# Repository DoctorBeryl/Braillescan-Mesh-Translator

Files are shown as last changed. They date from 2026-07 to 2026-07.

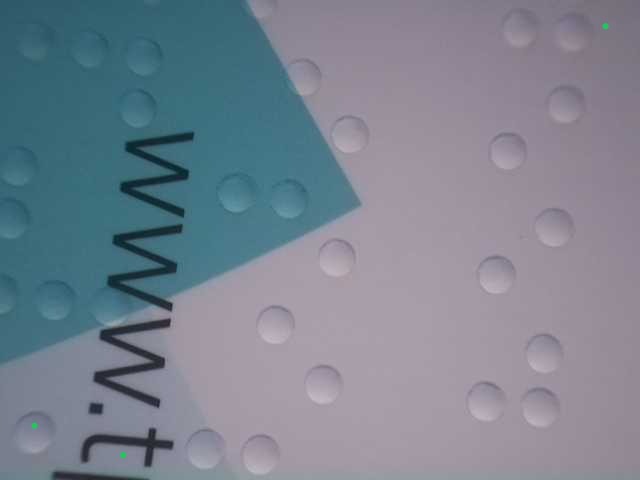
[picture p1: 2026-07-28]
test_images/input/img-1785229373890.jpg

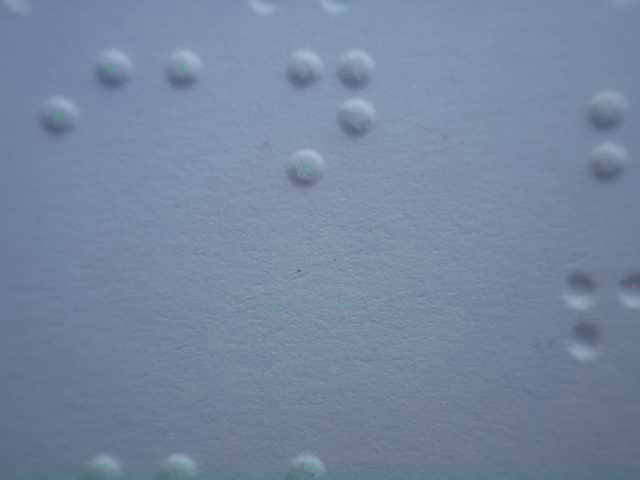
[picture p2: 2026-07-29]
test_images/input/clean2.jpg

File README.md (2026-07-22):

# BrailleScan Mesh Translator

**Dispozitiv bazat pe Raspberry Pi care recunoaște și traduce text Braille și text tipărit, utilizând o cameră cu lentilă macro, senzori, o interfață web și un afișaj LCD.**

---

### Documentele esențiale:

| Document | Link |
|---|---|
| **DOCUMENTATIE** | [Documentatie](#descrierea-problemei-pe-care-o-rezolvăm) |
| **COMENZI SETUP** | [SETUP_COMMANDS.txt](./SETUP_COMMANDS.txt) |
| **Hardware Necesar** | [Hardware](#cerințe-hardware) |
| **Modele 3D** | [3dmodels/](./3dmodels/) |

---

## Comenzi Rapide - Setup Website

```bash
git clone https://github.com/DoctorBeryl/Braillescan-Mesh-Translator.git
cd Braillescan-Mesh-Translator
npm install
npm install concurrent --save-dev
npm run dev
```

Accesare: http://192.168.100.184:3000

**Instalare completă:** [SETUP_COMMANDS.txt](./SETUP_COMMANDS.txt)

---

## Stack Tehnologic

- **Frontend:** React 19, Vite 8, Tailwind CSS 4
- **Backend:** Node.js, Express 5
- **Hardware:** libcamera/rpicam, nmcli, I2C/SPI
- **Tools:** Oxlint, Concurrently

---

## Dependințe

### Runtime
| Pachet | Versiune | Scop |
|---|---|---|
| react | ^19.2.7 | Framework UI |
| express | ^5.1.0 | Server HTTP |
| @google/model-viewer | ^4.3.1 | Vizualizare 3D |
| @vitalets/google-translate-api | ^9.2.1 | Traducere |
| lucide-react | ^1.24.0 | Pictograme |

### Sistem
- Raspberry Pi 3 A+ (sau mai nou)
- Raspberry Pi OS Bookworm
- Node.js 18+
- libcamera/rpicam
- i2c-tools

---

## Cerințe Hardware

- Raspberry Pi 3 A+ (Pi 4/5 recomandat)
- Card microSD 32GB+
- Sursă 5V/2A
- Camera Raspberry Pi Module 3 cu lentilă macro
- Display LCD I2C/SPI (16x2 sau 20x4)
- Senzori distanță (VL53L0X)
- Wi-Fi încorporat

**Modele 3D:** Disponibile în directorul `3dmodels/` pentru tipărire

---

## Cuprins

- [Descrierea Problemei](#descrierea-problemei-pe-care-o-rezolvăm)
- [Soluția Propusă](#descrierea-soluției-propuse)
- [Publicul Țintă](#definirea-publicului-țintă)
- [Funcționalități](#prezentarea-funcționalităților-aplicației)
- [Arhitectura](#arhitectura-aplicației)
- [Puncte Forte](#elemente-distinctive-ale-aplicației--puncte-forte)
- [Justificare Tehnologii](#justificarea-folosirii-tehnologiilor-alese)
- [Opinia Autorilor](#opinia-autorilor-despre-proiect)
- [Roadmap](#roadmap)

---

# BrailleScan Mesh Translator — Documentație proiect

## Descrierea problemei pe care o rezolvăm

Accesul persoanelor cu deficiențe de vedere la informațiile scrise
reprezintă încă o provocare majoră. Deși sistemul Braille este
standardul internațional pentru citirea tactilă, un număr redus de
persoane din populația generală cunosc acest sistem de scriere. În
consecință, membrii familiei, profesorii, voluntarii sau alte persoane
care interacționează cu utilizatorii nevăzători întâmpină dificultăți în
interpretarea documentelor redactate în Braille.

Pe de altă parte, dispozitivele realizate în cadrul unor programe
universitare sau a unor producători comerciali, dedicate traducerii
Braille în text obișnuit, nu sunt accesibile publicului, iar costurile
acestora se ridică la sute sau chiar mii de dolari. Acestea utilizează
componente specializate și oferă o flexibilitate redusă în ceea privește
costurile. De asemenea, majoritatea soluțiilor existente sunt orientate
exclusiv către conversia textului tipărit în Braille sau necesită
echipamente profesionale pentru scanare.

BrailleScan Mesh Translator își propune să elimine aceste limitări prin
dezvoltarea unui dispozitiv accesibil, portabil și ușor de utilizat,
capabil să traducă atât textul Braille embosat, cât și textul tipărit
obișnuit, utilizând tehnologii moderne de procesare a imaginilor și
senzori dedicați.

## Descrierea soluției propuse

BrailleScan Mesh Translator este un aparat electronic
construit în jurul unui microcalculator Raspberry Pi. Dispozitivul
utilizează o cameră echipată cu lentilă macro pentru captarea în detaliu
a suprafeței hârtiei embosate și senzori care permit analizarea
reliefului caracterelor Braille.

Imaginea captată este procesată, fiind identificată poziția punctelor
Braille și reconstruit caracterul corespunzător. Rezultatul este apoi
tradus automat în alfabetul latin și afișat pe interfața web.
Totodată, aparatul oferă indicații în timp real despre poziția optimă a
camerei pe un ecran LCD integrat.

În plus, dispozitivul poate funcționa și ca un scanner OCR pentru text
obișnuit, utilizând aceeași cameră și algoritmi de recunoaștere optică a
caracterelor.

Întregul sistem este accesibil prin intermediul unei aplicații web
găzduite chiar pe Raspberry Pi, fără a necesita instalarea unui software
suplimentar pe calculatorul utilizatorului. De asemenea, aparatul este
portabil, fiind încadrat într-un cadru printat 3D, ceea ce îi permite
utilizarea în contexte diverse. Acesta nu depinde permanent de o sursă
fixă de curent.

## Definirea publicului țintă

Proiectul este destinat în principal:

- Persoanelor cu deficiențe de vedere
- Profesorilor care predau alfabetul Braille
- Instituțiilor de învățământ special
- Bibliotecilor pentru nevăzători
- Membrilor familiei persoanelor nevăzătoare
- Voluntarilor și organizațiilor care lucrează în domeniul incluziunii sociale

De asemenea, dispozitivul poate fi utilizat în scop educațional pentru
familiarizarea persoanelor fără deficiențe de vedere cu sistemul Braille.

## Prezentarea funcționalităților aplicației

Principalele funcționalități ale sistemului sunt:

- Recunoașterea caracterelor Braille utilizând camera macro și senzorii dedicați
- Traducerea automată a textului Braille în alfabetul latin
- Recunoașterea textului tipărit prin tehnologia OCR
- Afișarea indicațiilor în timp real pe display-ul LCD
- Reconstruirea unei reprezentări 3D a textului Braille
- Accesarea unei interfețe web moderne prin intermediul browserului
- Funcționarea independentă într-o rețea Wi-Fi creată de Raspberry Pi
- Posibilitatea conectării la Internet printr-o a doua interfață wireless
- Administrarea și configurarea dispozitivului din interfața web

## Arhitectura aplicației

Sistemul este alcătuit din două componente principale:

**Dispozitivul Raspberry Pi** - Nucleul aplicației:
- Rularea sistemului de operare Linux
- Controlul camerei și al senzorilor
- Capturarea și distribuirea imaginilor pentru procesare
- Găzduirea aplicației web
- Streamingul camerei live pe interfață
- Administrarea rețelei locale

Raspberry Pi creează o rețea Wi-Fi proprie (Access Point). Opțional, poate folosi o a doua interfață Wi-Fi pentru conectarea la Internet. Hardware-ul este montat într-un cadru printat 3D modular. Dispozitivul necesită 5V la 2A. Utilizarea unui acumulator portabil permite funcționarea mobilă.

**Dispozitivul Host** - Orice calculator, tabletă sau telefon mobil cu browser web modern care comunică prin HTTP cu dispozitivul.

## Elemente distinctive ale aplicației — puncte forte

- Captură de imagini în mod macro pentru analizarea reliefului Braille
- Combinarea informațiilor provenite din senzori și procesarea imaginilor
- Suport simultan pentru traducerea Braille și OCR
- Traducerea directă în sau din diferite limbi străine
- Funcționalitate offline
- Interfață web multiplatformă, fără aplicații dedicate
- Cost redus comparativ cu echipamentele comerciale
- Arhitectură modulară și extensibilă

## Justificarea folosirii tehnologiilor alese

Platforma Raspberry Pi 3 A+ oferă un raport excelent între performanță, consum energetic și cost. Dispune de suficientă putere de procesare pentru analizarea imaginilor în timp real și permite integrarea facilă cu camere și senzori. Linux oferă stabilitate și suport extins pentru biblioteci open-source.

Interfața web este independentă de sistemul de operare și poate fi accesată de pe orice dispozitiv cu browser. Camera cu lentilă macro permite captarea fidelă a reliefului Braille. Alegerea acestor tehnologii conduce la un sistem flexibil, ușor de întreținut și extensibil.

## Opinia autorilor despre proiect

Considerăm că beneficiile tehnologiei trebuie să fie disponibile unui
număr cât mai mare de persoane. Asistența persoanelor cu dizabilități
reprezintă un scop important al acestui proiect. Noi am realizat
o soluție bazată pe componente relativ accesibile.

Un profesor care primește o lucrare redactată în Braille poate utiliza
BrailleScan Mesh Translator pentru a obține rapid traducerea în alfabetul latin.
Membrii familiei pot înțelege mai ușor mesajele scrise în Braille,
facilitând comunicarea zilnică.

## Roadmap

Pentru etapele ulterioare ale dezvoltării propunem:

- Creșterea vitezei de recunoaștere
- Integrarea unui display Braille reîmprospătabil pentru conversia inversă
- Integrarea unui sintetizator vocal
- Dezvoltarea unei aplicații mobile dedicate
- Sincronizarea cu servicii cloud
- Îmbunătățirea autonomiei și optimizarea designului cadrului printat 3D
- Integrarea sistemelor de inteligență artificială pentru optimizarea recunoașterii
- Implementarea unui sistem autofocus pentru cameră

**Repository:** https://github.com/DoctorBeryl/Braillescan-Mesh-Translator
**Mentenanță:** [@DoctorBeryl](https://github.com/DoctorBeryl)

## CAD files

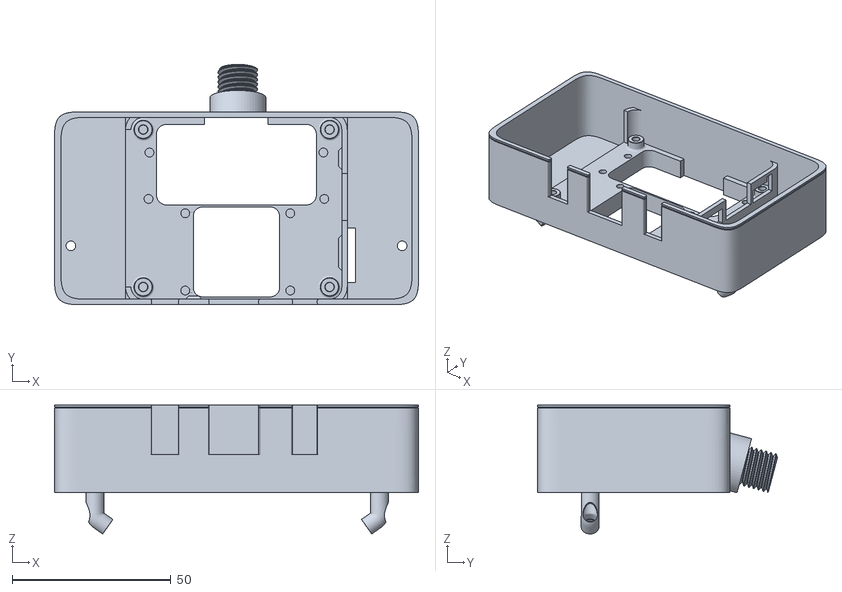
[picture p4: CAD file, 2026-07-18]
3dmodels/MainHolder.stl
114.7 x 75.7 x 40.6

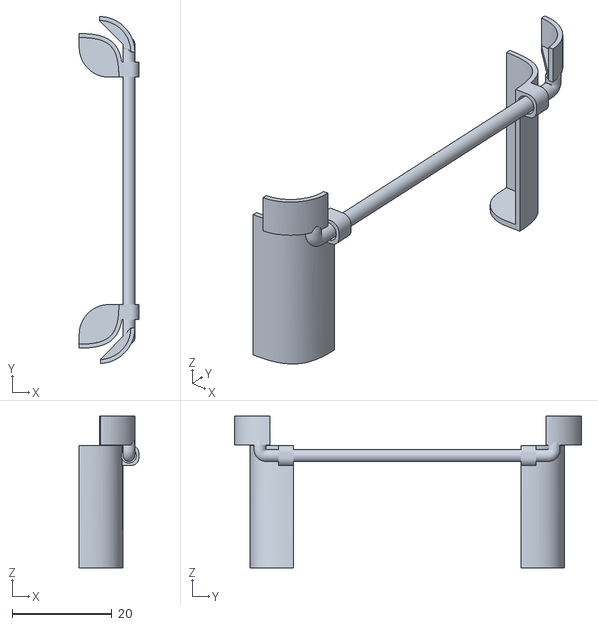
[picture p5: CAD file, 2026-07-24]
3dmodels/coverextras2.stl
12.0 x 69.5 x 30.4

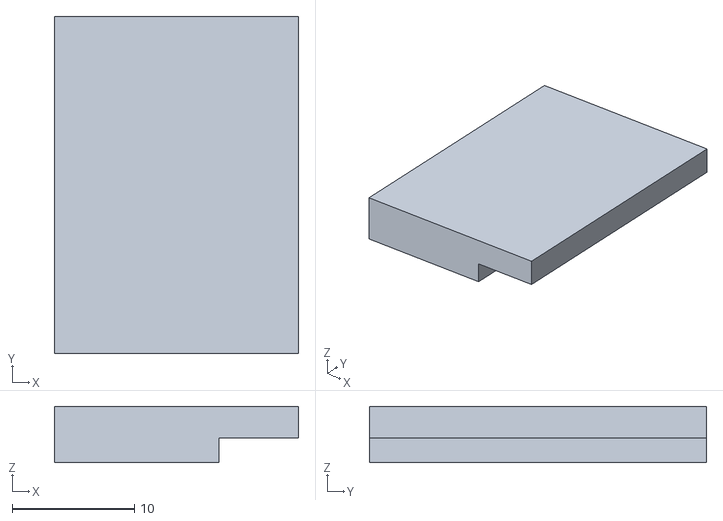
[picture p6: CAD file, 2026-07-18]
3dmodels/CameraExtras.stl
20.0 x 27.6 x 4.60

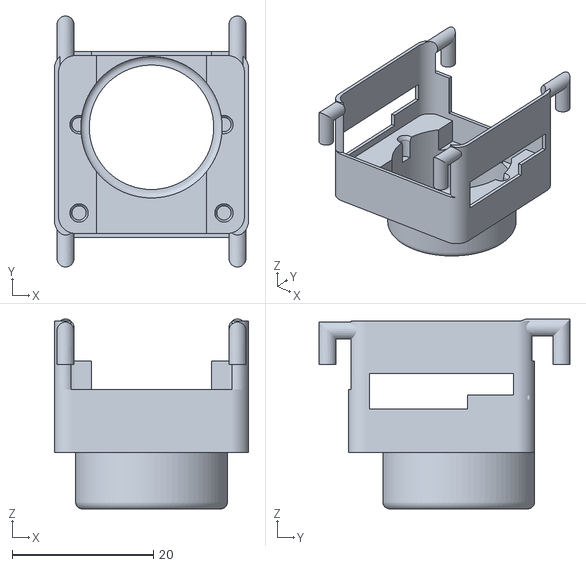
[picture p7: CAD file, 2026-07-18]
3dmodels/RaspberryPiCameraModule3Cover.stl
27.5 x 35.5 x 26.9

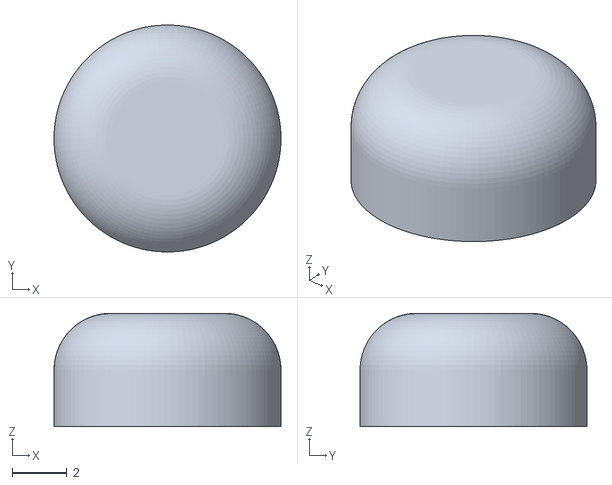
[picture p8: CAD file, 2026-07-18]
3dmodels/CoverExtras.stl
8.32 x 8.32 x 4.16

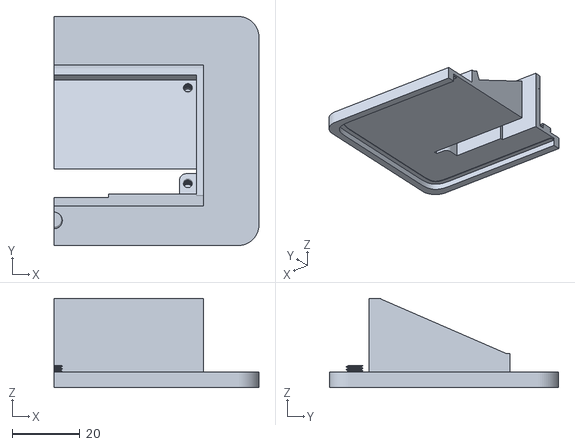
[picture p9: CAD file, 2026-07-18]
3dmodels/CoverRight.stl
60.4 x 67.5 x 26.3

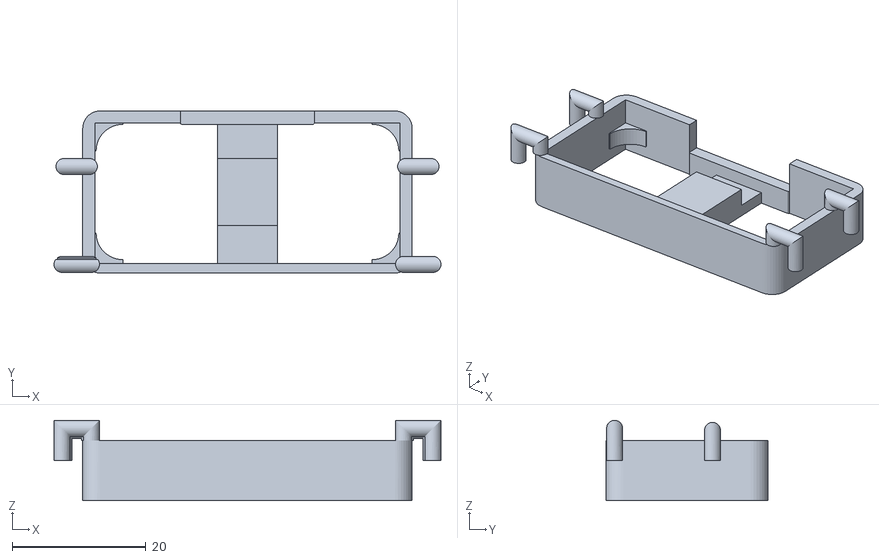
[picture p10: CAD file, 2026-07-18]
3dmodels/DistanceSensorCover.stl
57.8 x 24.2 x 12.0

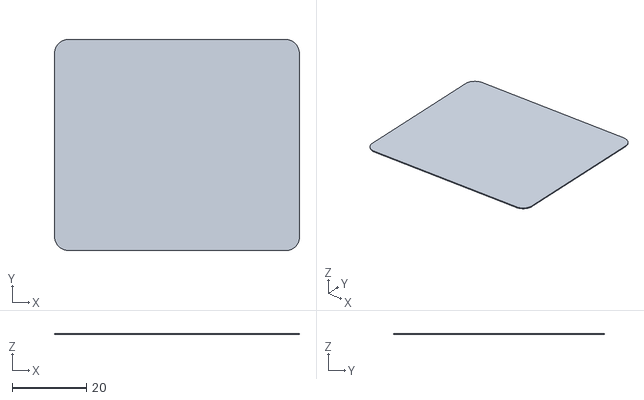
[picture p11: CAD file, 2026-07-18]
3dmodels/RaspberryPiFlooring.stl
66.0 x 56.9 x 0.3

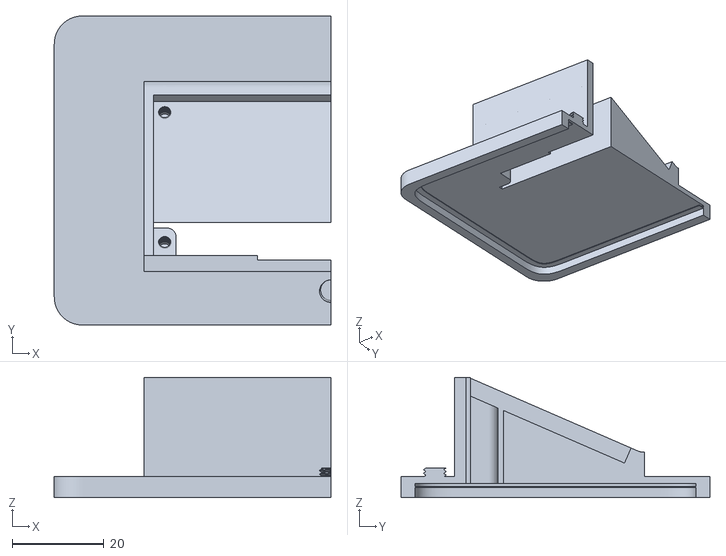
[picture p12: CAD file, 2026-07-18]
3dmodels/CoverLeft.stl
60.4 x 67.5 x 26.3

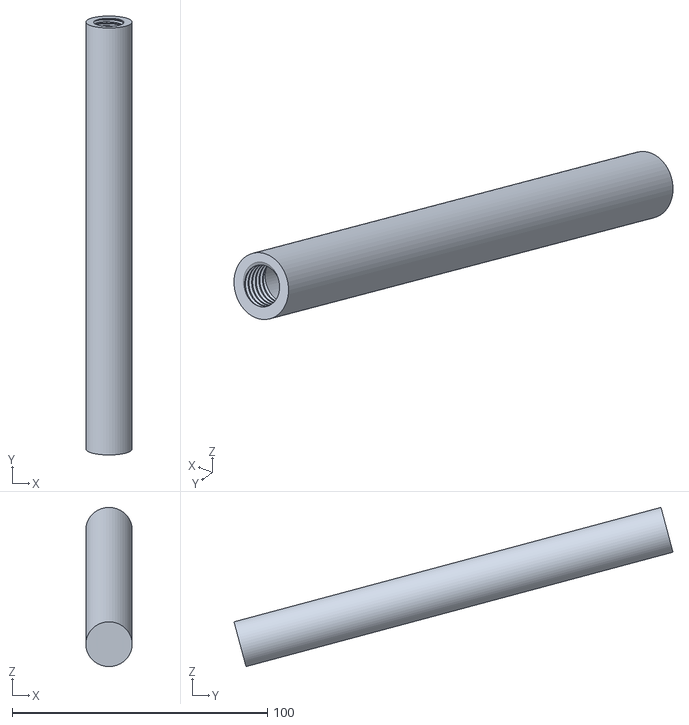
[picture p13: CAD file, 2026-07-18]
3dmodels/Handle.stl
18.1 x 172.1 x 62.4

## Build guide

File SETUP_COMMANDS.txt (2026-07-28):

================================================================================
    BRAILLESCAN MESH TRANSLATOR - COMENZI SETUP (MINIM)
================================================================================

CUPRINS:
  1. Setup Dezvoltare (Calculator Local)
  2. Instalare Raspberry Pi OS
  3. Setup Inițial Sistem
  4. Instalare Aplicație pe Raspberry Pi
  5. Pornire Aplicație
  6. Setup Serviciu Systemd (Auto-start)
  7. Ecran LCD 16x2 (Instrucțiuni la Boot)
  8. Permisiuni Admin (Reboot / Poweroff din interfața web)

================================================================================
1. SETUP DEZVOLTARE (Calculator Local)
================================================================================

Clonare și setup:
  git clone https://github.com/DoctorBeryl/Braillescan-Mesh-Translator.git
  cd Braillescan-Mesh-Translator
  npm install

Pornire:
  npm run dev

Build producție:
  npm run build
  npm run server

================================================================================
2. INSTALARE RASPBERRY PI OS
================================================================================

1. Descărcați Raspberry Pi Imager: https://www.raspberrypi.com/software/
2. Selectați: Raspberry Pi OS Lite 64-bit
3. Flash pe card microSD
4. Boot și conectare SSH: ssh pi@raspberrypi.local

================================================================================
3. SETUP INIȚIAL SISTEM
================================================================================

Update sistem:
  sudo apt update && sudo apt upgrade -y

Activare interfețe (raspi-config):
  sudo raspi-config
  # Interfacing Options → Camera, I2C, SPI, SSH → Enable
  # Reboot

Instalare dependințe:
  sudo apt install -y git curl build-essential libcamera-apps i2c-tools
  curl -fsSL https://deb.nodesource.com/setup_20.x | sudo -E bash -
  sudo apt install -y nodejs npm

================================================================================
4. INSTALARE APLICAȚIE PE RASPBERRY PI
================================================================================

Clonare și setup:
  cd ~
  git clone https://github.com/DoctorBeryl/Braillescan-Mesh-Translator.git
  cd Braillescan-Mesh-Translator
  npm install

================================================================================
5. PORNIRE APLICAȚIE
================================================================================

Pornire mod dezvoltare:
  cd ~/Braillescan-Mesh-Translator
  npm run dev

Accesare browser:
  http://192.168.100.184:3000
  
================================================================================
6. SETUP SERVICIU SYSTEMD (Auto-start la Boot)
================================================================================

Creare serviciu:
  sudo nano /etc/systemd/system/braillescan.service

Adăugați:
---
[Unit]
Description=BrailleScan Mesh Translator
After=network.target

[Service]
Type=simple
User=pi
WorkingDirectory=/home/pi/Braillescan-Mesh-Translator
ExecStart=/usr/bin/npm run dev
Restart=always

[Install]
WantedBy=multi-user.target
---

Salvare (Ctrl+X, Y, Enter)

Activare:
  sudo systemctl daemon-reload
  sudo systemctl enable braillescan.service
  sudo systemctl start braillescan.service

Comenzi serviciu:
  sudo systemctl status braillescan.service   # Status
  sudo systemctl restart braillescan.service  # Restart
  sudo journalctl -u braillescan.service -f   # Logs

================================================================================
7. ECRAN LCD 16x2 (Instrucțiuni la Boot + Live Scan)
================================================================================

Afișează în buclă, imediat după boot, cei 3 pași de conectare (WLAN, adresa
serverului, pornirea camerei) -- util fără monitor/SSH conectat.

Odată ce serverul Node raportează stream-ul camerei ca activ, ecranul trece
automat la afișarea live: rândul 2 arată distanța curentă până la suprafață
și diferența față de distanța focală ideală (4.8cm); rândul 1 rămâne gol
decât dacă imaginea e neclară, caz în care spune "Move closer"/"Move
farther" dacă distanța e departe de punctul focal, sau "Image blurred" dacă
distanța e ok dar imaginea tot neclară. Dacă stream-ul se oprește, revine
la instrucțiunile de boot.

Cablaj (RW la GND, doar scriere):
  RS -> GPIO25   E -> GPIO24
  D4 -> GPIO23   D5 -> GPIO17   D6 -> GPIO18   D7 -> GPIO22
  VO -> potențiometru 10k (contrast)

Scriptul (server/lcd.py) folosește RPi.GPIO, deja în requirements.txt.

Creare serviciu:
  sudo nano /etc/systemd/system/braillescan-lcd.service

Adăugați:
---
[Unit]
Description=BrailleScan LCD Boot Instructions
After=local-fs.target

[Service]
Type=simple
User=pi
WorkingDirectory=/home/pi/Braillescan-Mesh-Translator/server
ExecStart=/usr/bin/python3 lcd.py
Restart=always

[Install]
WantedBy=multi-user.target
---

Salvare (Ctrl+X, Y, Enter)

Activare:
  sudo systemctl daemon-reload
  sudo systemctl enable braillescan-lcd.service
  sudo systemctl start braillescan-lcd.service

Comenzi serviciu:
  sudo systemctl status braillescan-lcd.service   # Status
  sudo systemctl restart braillescan-lcd.service  # Restart
  sudo journalctl -u braillescan-lcd.service -f   # Logs

================================================================================
8. PERMISIUNI ADMIN (Reboot / Poweroff / Wi-Fi din interfața web)
================================================================================

Meniul Admin din aplicație rulează "sudo -n reboot" și "sudo -n poweroff".
Meniul Wi-Fi (scanare, status, conectare pe wlan1) și comanda "Restart
Wi-Fi interface" rulează "sudo -n nmcli ...". Flag-ul -n interzice sudo să
ceară parola interactiv (procesul Node nu are un terminal atașat), deci
dacă utilizatorul "pi" nu are sudo fără parolă configurat pentru aceste
comenzi, ele eșuează imediat cu eroarea "sudo: a password is required" —
acesta este motivul cel mai probabil pentru care meniul Admin sau meniul
Wi-Fi nu funcționează.

Aflați calea reală a binarelor (poate diferi de exemplul de mai jos):
  which reboot poweroff nmcli

Adăugați o regulă NOPASSWD doar pentru aceste comenzi (recomandat, nu
pentru tot sudo):
  sudo visudo -f /etc/sudoers.d/braillescan-admin

Introduceți (ajustați căile dacă "which" a arătat altceva):
  pi ALL=(ALL) NOPASSWD: /usr/sbin/reboot, /usr/sbin/poweroff, /usr/bin/nmcli

Salvare (Ctrl+X, Y, Enter) — visudo validează sintaxa automat înainte de
a scrie fișierul, deci o greșeală de sintaxă nu vă poate bloca sudo-ul.

Verificare (fără să reporniți efectiv dispozitivul):
  sudo -n -l
  # Comenzile "reboot", "poweroff" și "nmcli" trebuie să apară cu (NOPASSWD)

================================================================================
COMENZI RAPIDE
================================================================================

npm run dev       - Pornire mod dezvoltare
npm run build     - Build producție
npm run server    - Pornire server (după build)
npm run lint      - Rulare linter

===============================================================================

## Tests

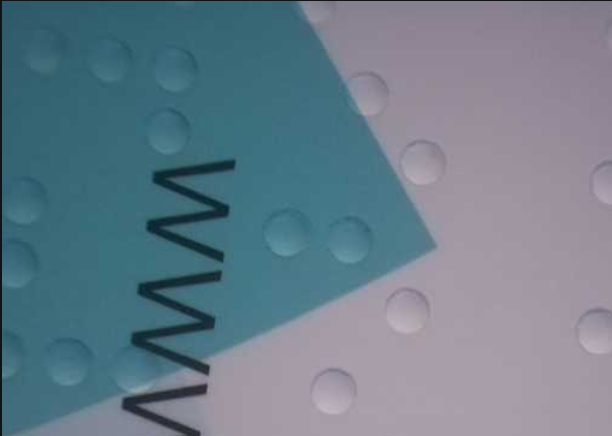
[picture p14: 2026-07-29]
test_images/input_new/Screenshot 2026-07-29 071821.png

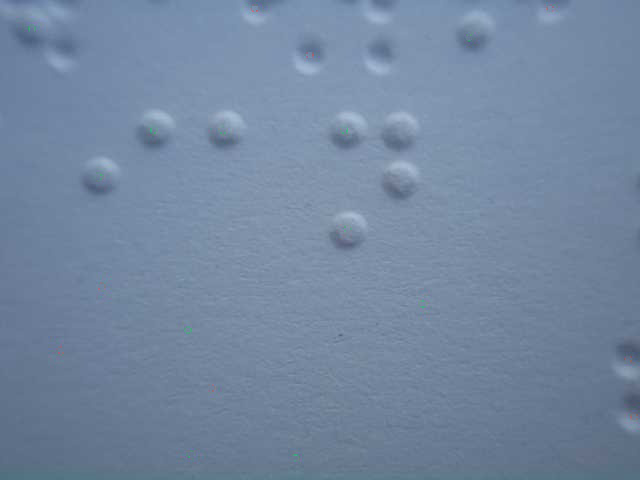
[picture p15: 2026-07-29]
test_images/input/clean1.jpg

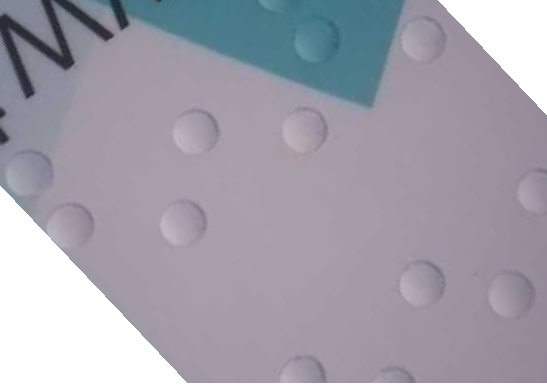
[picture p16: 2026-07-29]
test_images/input_new/Screenshot 2026-07-29 07173832.png

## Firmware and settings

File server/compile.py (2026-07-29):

"""Builds a composite of the scanned Braille surface out of the raw camera stills.

Pipeline: clean output/ -> for each image in input/, skip it unless it's
sharp -> detect the braille dot centers in it, along with each dot's
raking-light polarity (bump facing the camera vs. a dimple facing away, see
classify_dot_polarity) -> try to align it onto an existing output image by
finding a rotation+translation that lines up enough of its dots (position
*and* polarity) with that image's dots -> if nothing correlates, seed a new
output image with it -> clean input/.

Alignment is done from the dot *positions* rather than generic ORB/SIFT
features: a braille dot grid is highly repetitive texture, so descriptor
matching on the dots themselves (or on the surrounding paper) is unreliable -
lots of dots look alike. Two dot grids that really overlap, however, share a
large set of points related by a single rigid transform (the camera only
translates/rotates between shots, it doesn't warp the paper), so a RANSAC
search over that transform is a much more direct fit for this data than
feature descriptors are.

Position alone is still ambiguous on a periodic grid: a transform that's off
by exactly one dot pitch lines up almost as many points as the true one does,
since every dot has a look-alike neighbor one pitch away in each direction.
Each dot's polarity (see src/lib/crescentDetect.js's classifyDotDirection,
which this mirrors) breaks that tie - it's read straight off the raking-light
shading and doesn't depend on position at all, so requiring it to agree is an
independent check that a merely periodic mismatch can't satisfy by accident.
"""
import glob
import json
import os
import shutil
import sys
import time
from collections import defaultdict

import cv2
import numpy as np

SERVER_DIR = os.path.dirname(os.path.abspath(__file__))
INPUT_DIR = os.path.join(SERVER_DIR, '..', 'raspimages')
OUTPUT_DIR = os.path.join(SERVER_DIR, '..', 'output')
RAW_DEBUG_DIR = os.path.join(SERVER_DIR, '..', 'raw_debug')
# clean_dir(INPUT_DIR) below deletes every raw still once it's been read, so a
# run's true inputs are otherwise unrecoverable for offline tuning. Set
# COMPILE_KEEP_RAW=1 (see server/index.js's /api/compile handler) to archive
# an untouched copy of this run's raw captures before that cleanup runs.
KEEP_RAW_COPIES = os.environ.get('COMPILE_KEEP_RAW') == '1'

SHARPNESS_THRESHOLD = 100.0   # variance of Laplacian; below this, image is too blurry
# Laplacian variance scales with resolution (more pixels means more high-frequency
# detail for the same real sharpness), so it's only comparable to a fixed
# threshold at a fixed sample size. Matches src/lib/sharpness.js's
# SHARPNESS_SAMPLE_WIDTH/HEIGHT so a photo the client already judged sharp isn't
# re-judged blurry here just because it's being read at full camera resolution.
SHARPNESS_SAMPLE_WIDTH = 160
SHARPNESS_SAMPLE_HEIGHT = 120

# Dot detection. Same size-fraction assumptions as src/lib/crescentDetect.js
# (MIN/MAX_RADIUS_FRACTION), since both read the same physical setup: a fixed
# focal distance, so a dot's radius as a fraction of the frame is stable.
DOT_MIN_RADIUS_FRACTION = 0.035
DOT_MAX_RADIUS_FRACTION = 0.085
MAX_DOTS_PER_IMAGE = 150      # bounds RANSAC cost; excess low-confidence circles are dropped
# A real embossed dot sits right at DOT_MIN_RADIUS_FRACTION's boundary (measured
# ~17px against a min_r of 17px on a 640x480 capture), so cv2.HoughCircles's
# accumulator threshold has to be permissive enough to clear that boundary
# consistently frame-to-frame. The previous value of 22 routinely missed most of
# a frame's real dots (sometimes all of them) on otherwise-sharp, otherwise-
# overlapping stills, starving the RANSAC alignment below of correspondences
# and splitting a single scanned surface into far more output pieces than the
# real overlap between shots warrants. _filter_to_radius_mode/_filter_to_grid
# below claw back the precision this costs by rejecting the extra
# low-confidence circles that a lower threshold lets through, rather than
# relying on the accumulator threshold alone to separate real dots from noise.
HOUGH_ACCUMULATOR_THRESHOLD = 12
# Mirrors src/lib/crescentDetect.js's filterToRadiusMode/filterToGrid: a real
# dot grid is far more uniform in dot size and spacing than the raw Hough
# candidate list, so keeping only candidates that agree with the frame's own
# dominant radius and lattice pitch discards noise-driven circles that a
# permissive HOUGH_ACCUMULATOR_THRESHOLD lets through, without having to fall
# back to a stricter (and less sensitive) accumulator threshold to do it.
RADIUS_MODE_MIN_CANDIDATES = 4
RADIUS_MODE_BUCKET_FRACTION = 0.25
RADIUS_MODE_TOLERANCE = 0.35
GRID_PITCH_MIN_CANDIDATES = 6
GRID_PITCH_BUCKET_FRACTION = 0.2
GRID_PITCH_MIN_BUCKET_SUPPORT = 2
# Includes diagonal lattice distances (sqrt(2), sqrt(5), 2*sqrt(2)) in addition to
# straight multiples, since a dot's nearest neighbor in a 2D grid is often
# diagonal rather than axis-aligned.
GRID_PITCH_MULTIPLES = (1.0, 2 ** 0.5, 2.0, 5 ** 0.5, 2 * 2 ** 0.5, 3.0)
GRID_PITCH_TOLERANCE = 0.25

# Polarity classification (bump-facing-camera vs. dimple-facing-away). Mirrors
# the constants in src/lib/crescentDetect.js so the two readings of the same
# physical dots agree.
LOCAL_BRIGHTNESS_SIGMA_RADIUS_MULTIPLE = 1.6
LOCAL_BRIGHTNESS_MIN_STD = 0.75
LOCAL_BRIGHTNESS_CLIP_STD = 2.5
# Sampling this close to the rim (previously 0.85-1.3r) put most of the band on or
# past the dot's own boundary, averaging in the flat paper beside it rather than the
# dome's own shading, which is strong across the whole disc, not just a thin ring at
# the edge. See src/lib/crescentDetect.js's matching change.
EDGE_SAMPLE_INNER_RADIUS_MULTIPLE = 0.15
EDGE_SAMPLE_OUTER_RADIUS_MULTIPLE = 0.95
EDGE_SAMPLE_RADIAL_STEPS = 6
EDGE_SAMPLE_HALF_ANGLE_SAMPLES = 16
DOT_DIRECTION_ANGLE_SAMPLES = 24

# Dot-based alignment (RANSAC over rigid transforms).
# 5 sounds low, but each inlier here is already load-bearing on its own: it has
# to land within POINT_MATCH_TOLERANCE_PX under a single shared rigid
# transform *and* agree in polarity, and a wrong-by-one-pitch transform (the
# periodic-grid ambiguity described up top) would have to fake that same
# polarity pattern at the grid's own period to slip through. That combination
# makes 5 clean inliers already a strong signal; real overlapping photos were
# being rejected one dot short of the old threshold of 6.
MIN_DOT_MATCHES = 5           # aligned dot pairs required to call two images connected
DOT_RANSAC_ITERATIONS = 800
POINT_MATCH_TOLERANCE_PX = 6.0   # how close a transformed dot must land to a real dot to count
PAIR_DISTANCE_TOLERANCE_PX = 4.0 # how closely two pivot-pair distances must agree to try a transform
MIN_PIVOT_DISTANCE_PX = 10.0     # ignore near-duplicate pivot points; their rotation estimate is unstable
# A grid is periodic, so many pivot pairs share the same spacing - once a
# transform already explains a clear majority of both dot sets there's
# nothing to gain from grinding through the rest of the RANSAC budget.
EARLY_EXIT_FRACTION = 0.6
MAX_CANVAS_DIMENSION = 6000   # guards against a bad transform blowing up the merged canvas
# The camera pans and rotates gently across a flat page between shots; it never
# flips past perpendicular. A transform that only barely clears MIN_DOT_MATCHES
# can still land on an implausible rotation (confirmed on real captures: a
# handful of noise-driven correspondences on a periodic dot grid occasionally
# line up at ~90-180 degrees), which then merges two unrelated crops into one
# canvas. Capping the accepted rotation rejects those without having to raise
# MIN_DOT_MATCHES (which would throw out genuine low-overlap matches too).
MAX_ALIGNMENT_ROTATION_DEGREES = 45.0

RNG = np.random.default_rng()


def clean_dir(path):
    for f in glob.glob(os.path.join(path, '*')):
        if os.path.isfile(f):
            os.remove(f)


def is_sharp(gray):
    # Resized to the same fixed sample size the client scores sharpness at
    # (see SHARPNESS_SAMPLE_WIDTH/HEIGHT above) before stretching to the full
    # 0-255 range -- stretch first, Laplacian variance scales with contrast as
    # well as focus, so a washed-out/flatly-lit still (embossed dots close in
    # tone to the background) would otherwise read as blurry even in perfect
    # focus. See src/lib/sharpness.js for the matching client-side check.
    small = cv2.resize(gray, (SHARPNESS_SAMPLE_WIDTH, SHARPNESS_SAMPLE_HEIGHT))
    stretched = cv2.normalize(small, None, 0, 255, cv2.NORM_MINMAX)
    return cv2.Laplacian(stretched, cv2.CV_64F).var() >= SHARPNESS_THRESHOLD


def _bilinear_sample(field, x, y):
    h, w = field.shape
    cx = min(max(x, 0.0), w - 1.001)
    cy = min(max(y, 0.0), h - 1.001)
    x0, y0 = int(cx), int(cy)
    x1, y1 = x0 + 1, y0 + 1
    wx, wy = cx - x0, cy - y0
    v00, v01 = field[y0, x0], field[y0, x1]
    v10, v11 = field[y1, x0], field[y1, x1]
    top = v00 + (v01 - v00) * wx
    bottom = v10 + (v11 - v10) * wx
    return top + (bottom - top) * wy


def _sample_ring_direction_vector(relative, cx, cy, r):
    """Each candidate dot's own ring is a clean read of its bump's
    bright-to-dark axis: sampling only reaches pixels within EDGE_SAMPLE's
    band around that one dot, so it can't pick up a page-wide brightness
    blob. Returns a (vx, vy) vector: the angle a real embossed dot's own
    brightness peaks toward, weighted by how pronounced that peak is (a
    near-flat ring, e.g. from a false-positive candidate, contributes little).
    """
    inner = r * EDGE_SAMPLE_INNER_RADIUS_MULTIPLE
    outer = r * EDGE_SAMPLE_OUTER_RADIUS_MULTIPLE
    steps = EDGE_SAMPLE_RADIAL_STEPS
    samples = DOT_DIRECTION_ANGLE_SAMPLES
    values = np.empty(samples, dtype=np.float64)
    for a in range(samples):
        theta = (a / samples) * 2 * np.pi
        total = 0.0
        for s in range(steps):
            frac = 0.5 if steps == 1 else s / (steps - 1)
            sample_r = inner + frac * (outer - inner)
            sx = cx + np.cos(theta) * sample_r
            sy = cy + np.sin(theta) * sample_r
            total += _bilinear_sample(relative, sx, sy)
        values[a] = total / steps

    mean = values.mean()
    vx = 0.0
    vy = 0.0
    for a in range(samples):
        theta = (a / samples) * 2 * np.pi
        weight = values[a] - mean
        vx += np.cos(theta) * weight
        vy += np.sin(theta) * weight
    return vx, vy


def estimate_consensus_light_angle(relative, points, radii):
    """A single sum-then-arctan2 over the whole frame's own pixel gradient -
    or a smoothed field of it - conflates the raking light's genuinely subtle
    shading with any large, unrelated brightness contrast the frame happens
    to contain: the page sitting on a darker table, a printed logo, a shadow.
    That contrast is far stronger than the light's own gradient, so it
    dominates the estimate. Measured on a real capture with a visible
    page/table boundary, plotting that frame-gradient direction as a hue
    wheel across the image showed a textbook vortex centered on the page -
    i.e. it was reading "which way is the brighter paper from here", not the
    actual light source, which misclassified every dot near that boundary.

    Since real embossed dots on one page are physically bumps of one
    consistent handedness, summing every candidate's own ring axis (see
    _sample_ring_direction_vector) into one consensus vector recovers the
    true light direction for the whole page without ever touching a
    page-level pixel gradient.
    """
    sum_x = 0.0
    sum_y = 0.0
    for (cx, cy), r in zip(points, radii):
        vx, vy = _sample_ring_direction_vector(relative, cx, cy, r)
        sum_x += vx
        sum_y += vy
    return float(np.arctan2(sum_y, sum_x))


def local_relative_brightness(gray, sigma):
    """Per-pixel brightness expressed as a clipped z-score against its own
    local neighborhood, so shading is comparable across differently-lit
    regions of the same page."""
    gray_f = gray.astype(np.float32)
    mean = cv2.GaussianBlur(gray_f, (0, 0), sigma)
    mean_sq = cv2.GaussianBlur(gray_f * gray_f, (0, 0), sigma)
    variance = np.maximum(0, mean_sq - mean * mean)
    std = np.sqrt(variance)
    clip = LOCAL_BRIGHTNESS_CLIP_STD
    with np.errstate(divide='ignore', invalid='ignore'):
        z = np.where(std > LOCAL_BRIGHTNESS_MIN_STD, (gray_f - mean) / std, 0.0)
    z = np.clip(z, -clip, clip)
    return ((z + clip) / (2 * clip)) * 255.0


def _sample_half_ring_brightness(relative, cx, cy, r, center_angle):
    """Average locally-normalized brightness over the half of the dot's disc
    centered on center_angle (a 180-degree wedge), sampled across most of the
    disc's radius rather than just a thin band at the rim."""
    inner = r * EDGE_SAMPLE_INNER_RADIUS_MULTIPLE
    outer = r * EDGE_SAMPLE_OUTER_RADIUS_MULTIPLE
    steps = EDGE_SAMPLE_RADIAL_STEPS
    samples = EDGE_SAMPLE_HALF_ANGLE_SAMPLES
    total = 0.0
    for s in range(steps):
        frac = 0.5 if steps == 1 else s / (steps - 1)
        sample_r = inner + frac * (outer - inner)
        for a in range(samples):
            theta = center_angle - np.pi / 2 + ((a + 0.5) / samples) * np.pi
            sx = cx + np.cos(theta) * sample_r
            sy = cy + np.sin(theta) * sample_r
            total += _bilinear_sample(relative, sx, sy)
    return total / (steps * samples)


def classify_dot_polarity(gray, enhanced, points, radii):
    """For each dot, compare brightness on the side of its rim facing the
    page's light source against the far side. A convex bump's near rim
    catches the light directly and reads bright while its far rim
    self-shadows; a concave dimple is the mirror image. Returns a bool array,
    True where the dot reads as a bump facing the camera."""
    if len(points) == 0:
        return np.empty((0,), dtype=bool)

    sigma = float(np.max(radii)) * LOCAL_BRIGHTNESS_SIGMA_RADIUS_MULTIPLE if len(radii) else 1.0
    relative = local_relative_brightness(enhanced, max(sigma, 1.0))
    light_angle = estimate_consensus_light_angle(relative, points, radii)

    polarity = np.empty(len(points), dtype=bool)
    for i, ((cx, cy), r) in enumerate(zip(points, radii)):
        toward = _sample_half_ring_brightness(relative, cx, cy, r, light_angle)
        away = _sample_half_ring_brightness(relative, cx, cy, r, light_angle + np.pi)
        polarity[i] = toward > away
    return polarity


def _filter_to_radius_mode(points, radii, weights):
    """Keep only candidates whose radius agrees with the frame's own dominant
    (vote-weighted) radius. Mirrors src/lib/crescentDetect.js's
    filterToRadiusMode - a real dot grid is one physical size, so a candidate
    far from that mode is almost always a noise-driven Hough hit rather than a
    dot HOUGH_ACCUMULATOR_THRESHOLD was too permissive about."""
    if len(points) < RADIUS_MODE_MIN_CANDIDATES:
        return points, radii, weights

    median = float(np.median(radii))
    bucket = max(1.0, median * RADIUS_MODE_BUCKET_FRACTION)
    keys = np.round(radii / bucket).astype(int)
    bucket_weight = defaultdict(float)
    for key, w in zip(keys.tolist(), weights.tolist()):
        bucket_weight[key] += w
    best_key = max(bucket_weight, key=bucket_weight.get)
    mode_radius = best_key * bucket

    mask = np.abs(radii - mode_radius) <= mode_radius * RADIUS_MODE_TOLERANCE
    if not mask.any():
        return points, radii, weights
    return points[mask], radii[mask], weights[mask]


def _estimate_grid_pitch(nn_distances):
    """The base dot pitch is the *smallest* recurring spacing, not the most
    common one - see the matching comment on estimateGridPitch in
    src/lib/crescentDetect.js, which this mirrors."""
    finite = np.sort(nn_distances[np.isfinite(nn_distances)])
    if len(finite) == 0:
        return None

    median = float(finite[len(finite) // 2])
    bucket = max(1.5, median * GRID_PITCH_BUCKET_FRACTION)
    keys = np.round(finite / bucket).astype(int)

    counts = defaultdict(int)
    for key in keys.tolist():
        counts[key] += 1

    smallest_supported = None
    best_key, best_count = None, 0
    for key, count in counts.items():
        if count > best_count:
            best_key, best_count = key, count
        if count >= GRID_PITCH_MIN_BUCKET_SUPPORT and (smallest_supported is None or key < smallest_supported):
            smallest_supported = key

    chosen = best_key if smallest_supported is None else smallest_supported
    return None if chosen is None else chosen * bucket


def _filter_to_grid(points, radii, weights):
    """Keep only candidates whose nearest neighbor sits at the frame's own
    lattice pitch (or a diagonal/straight multiple of it). Mirrors
    src/lib/crescentDetect.js's filterToGrid, discarding isolated
    noise-driven circles that don't belong to the dot grid at all."""
    if len(points) < GRID_PITCH_MIN_CANDIDATES:
        return points, radii, weights

    dists = np.sqrt(((points[:, None, :] - points[None, :, :]) ** 2).sum(axis=2))
    np.fill_diagonal(dists, np.inf)
    nn = dists.min(axis=1)

    pitch = _estimate_grid_pitch(nn)
    if not pitch:
        return points, radii, weights

    mask = np.zeros(len(points), dtype=bool)
    for multiple in GRID_PITCH_MULTIPLES:
        target = pitch * multiple
        mask |= np.abs(nn - target) <= target * GRID_PITCH_TOLERANCE

    if not mask.any():
        return points, radii, weights
    return points[mask], radii[mask], weights[mask]


def detect_dots(gray):
    """Return (points, polarity): an (N, 2) array of braille dot centers
    (x, y) in `gray`, and a matching (N,) bool array of each dot's polarity
    (see classify_dot_polarity)."""
    short = min(gray.shape)
    min_r = max(3, int(round(short * DOT_MIN_RADIUS_FRACTION)))
    max_r = max(min_r + 2, int(round(short * DOT_MAX_RADIUS_FRACTION)))

    enhanced = cv2.createCLAHE(clipLimit=3.0, tileGridSize=(8, 8)).apply(gray)
    blurred = cv2.GaussianBlur(enhanced, (5, 5), 1.2)
    circles = cv2.HoughCircles(
        blurred, cv2.HOUGH_GRADIENT, dp=1.2, minDist=max_r * 1.1,
        param1=80, param2=HOUGH_ACCUMULATOR_THRESHOLD, minRadius=min_r, maxRadius=max_r,
    )
    if circles is None:
        return np.empty((0, 2), dtype=np.float64), np.empty((0,), dtype=bool)

    points = circles[0][:, :2].astype(np.float64)[:MAX_DOTS_PER_IMAGE]
    radii = circles[0][:, 2].astype(np.float64)[:MAX_DOTS_PER_IMAGE]
    # cv2.HoughCircles doesn't expose each candidate's raw vote count, only the
    # rank it produces them in (strongest first) - used here as a stand-in
    # weight so the radius-mode vote below still favors more confident circles.
    weights = np.arange(len(points), 0, -1, dtype=np.float64)
    points, radii, weights = _filter_to_radius_mode(points, radii, weights)
    points, radii, _ = _filter_to_grid(points, radii, weights)

    polarity = classify_dot_polarity(gray, enhanced, points, radii)
    return points, polarity


def _similarity_from_pair(p1, p2, q1, q2):
    # Rotation+uniform-scale+translation that maps p1->q1 and p2->q2 exactly,
    # with no reflection (the camera only rotates/translates over the page).
    vp = p2 - p1
    vq = q2 - q1
    norm_vp = np.hypot(*vp)
    if norm_vp < 1e-6:
        return None
    scale = np.hypot(*vq) / norm_vp
    theta = np.arctan2(vq[1], vq[0]) - np.arctan2(vp[1], vp[0])
    c, s = np.cos(theta), np.sin(theta)
    r = scale * np.array([[c, -s], [s, c]])
    t = q1 - r @ p1
    return np.column_stack([r, t])


def _apply_transform(m, points):
    return (m[:, :2] @ points.T).T + m[:, 2]


def _rotation_degrees(m):
    return float(np.degrees(np.arctan2(m[1, 0], m[0, 0])))


def _count_inliers(m, pts_new, pts_base, pol_new, pol_base):
    """A candidate correspondence only counts if, on top of landing within
    POINT_MATCH_TOLERANCE_PX, its polarity agrees too. On a periodic grid the
    nearest point by distance alone is often just the next dot over rather
    than the true match, and a wrong-by-one-pitch transform can clear the
    same distance tolerance as the true one over most of the grid - polarity
    is read straight off the raking-light shading, independent of position,
    so requiring it to agree as well rejects those false matches instead of
    counting them as support for a bad transform."""
    transformed = _apply_transform(m, pts_new)
    dists = np.sqrt(((transformed[:, None, :] - pts_base[None, :, :]) ** 2).sum(axis=2))
    if len(pol_new) and len(pol_base):
        dists = np.where(pol_new[:, None] == pol_base[None, :], dists, np.inf)
    nearest_idx = dists.argmin(axis=1)
    nearest_dist = dists[np.arange(len(pts_new)), nearest_idx]
    mask = nearest_dist <= POINT_MATCH_TOLERANCE_PX
    return mask, nearest_idx
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

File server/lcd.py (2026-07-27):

"""Drives a 16x2 HD44780 LCD (4-bit mode) so the setup instructions are
visible immediately after boot, before a monitor or SSH session is available.

Wired directly to BCM GPIO (RW tied to GND -- write-only, no read needed):
  RS -> GPIO25   E -> GPIO24
  D4 -> GPIO23   D5 -> GPIO17   D6 -> GPIO18   D7 -> GPIO22

Runs as its own systemd service (see SETUP_COMMANDS.txt), independent of the
Node server -- these instructions are how the user finds that server in the
first place, so the boot-instructions loop can't depend on it being up.

Once the camera stream is live, switches to a live scan view instead: row 2
shows distance to the surface and its difference from the focal distance;
row 1 shows sharpness%, replaced by a reposition/blur warning when blurry.
"""
import json
import os
import signal
import time
import urllib.error
import urllib.request

import RPi.GPIO as GPIO

RS_PIN = 25
E_PIN = 24
DATA_PINS = (23, 17, 18, 22)  # D4, D5, D6, D7

LCD_WIDTH = 16
LINE1_ADDR = 0x80
LINE2_ADDR = 0xC0
DISPLAY_OFF_CMD = 0x08

E_PULSE_S = 0.0005
E_DELAY_S = 0.0005

STEPS = [
    ('Step 1/3', '1. Connect to WLAN "PiHotspot"'),
    ('Step 2/3', '2. Access 192.168.100.184:3000'),
    ('Step 3/3', '3. Tap Livestream, Enable Camera'),
]

SCROLL_STEP_S = 0.4
SCROLL_PAUSE_S = 1.5
STATIC_HOLD_S = 3

SERVER_BASE_URL = f'http://127.0.0.1:{os.environ.get("WIFI_SERVER_PORT", "3001")}'
HTTP_TIMEOUT_S = 1.0
# /api/distance spawns its own Python subprocess on the server and can
# legitimately take a while, especially while the camera stream is also
# eating CPU. This MUST stay comfortably above index.js's own
# DISTANCE_TIMEOUT_MS -- if the LCD gives up first, the field sits on "--"
# forever even though the server would have come back with a real reading a
# moment later.
DISTANCE_HTTP_TIMEOUT_S = 3.0
# /api/sharpness just serves back whatever the browser last POSTed -- no
# subprocess involved -- so this only needs to cover normal network latency.
SHARPNESS_HTTP_TIMEOUT_S = 1.5
SHARPNESS_POLL_INTERVAL_S = 1.0
SCAN_POLL_INTERVAL_S = 0.5

FOCAL_DISTANCE_CM = 4.8  # keep in sync with idealFocalDistanceCm in src/App.jsx
FOCAL_TOLERANCE_CM = 1


def lcd_toggle_enable():
    time.sleep(E_DELAY_S)
    GPIO.output(E_PIN, True)
    time.sleep(E_PULSE_S)
    GPIO.output(E_PIN, False)
    time.sleep(E_DELAY_S)


def lcd_send_nibble(nibble):
    for pin, bit in zip(DATA_PINS, (0, 1, 2, 3)):
        GPIO.output(pin, (nibble >> bit) & 1)
    lcd_toggle_enable()


def lcd_send_byte(byte, is_data):
    GPIO.output(RS_PIN, is_data)
    lcd_send_nibble(byte >> 4)
    lcd_send_nibble(byte & 0x0F)


def lcd_init():
    GPIO.setwarnings(False)
    GPIO.setmode(GPIO.BCM)
    GPIO.setup(RS_PIN, GPIO.OUT)
    GPIO.setup(E_PIN, GPIO.OUT)
    for pin in DATA_PINS:
        GPIO.setup(pin, GPIO.OUT)

    time.sleep(0.05)
    for command in (0x33, 0x32, 0x28, 0x0C, 0x06, 0x01):
        lcd_send_byte(command, is_data=False)
    time.sleep(0.005)


def lcd_write_line(text, addr):
    lcd_send_byte(addr, is_data=False)
    for char in text[:LCD_WIDTH].ljust(LCD_WIDTH):
        lcd_send_byte(ord(char), is_data=True)


def display_step(label, message):
    lcd_write_line(label, LINE1_ADDR)

    if len(message) <= LCD_WIDTH:
        lcd_write_line(message, LINE2_ADDR)
        time.sleep(STATIC_HOLD_S)
        return

    scroll_text = message + '  '
    doubled = scroll_text + scroll_text
    for offset in range(len(scroll_text)):
        lcd_write_line(doubled[offset:offset + LCD_WIDTH], LINE2_ADDR)
        time.sleep(SCROLL_STEP_S)
    time.sleep(SCROLL_PAUSE_S)


def fetch_json(path, timeout=HTTP_TIMEOUT_S):
    with urllib.request.urlopen(SERVER_BASE_URL + path, timeout=timeout) as response:
        return json.loads(response.read())


def fetch_streaming():
    try:
        return bool(fetch_json('/api/camera/stats').get('streaming'))
    except (urllib.error.URLError, OSError, ValueError):
        return False


def fetch_distance_cm():
    try:
        return fetch_json('/api/distance', timeout=DISTANCE_HTTP_TIMEOUT_S).get('distanceCm')
    except (urllib.error.URLError, OSError, ValueError):
        return None


def fetch_sharpness():
    try:
        data = fetch_json('/api/sharpness', timeout=SHARPNESS_HTTP_TIMEOUT_S)
        return data.get('blurry'), data.get('sharpnessPercent')
    except (urllib.error.URLError, OSError, ValueError):
        return None, None


def scan_lines(distance_cm, blurry, sharpness_percent):
    if distance_cm is None:
        line2 = 'Distance: --'
    else:
        diff_cm = distance_cm - FOCAL_DISTANCE_CM
        dist_text = f'{distance_cm:.1f}cm'
        diff_text = f'{diff_cm:+.1f}cm'
        line2 = dist_text.ljust(LCD_WIDTH - len(diff_text)) + diff_text

    if blurry and distance_cm is not None and abs(distance_cm - FOCAL_DISTANCE_CM) > FOCAL_TOLERANCE_CM:
        line1 = 'Move closer' if distance_cm > FOCAL_DISTANCE_CM else 'Move farther'
    elif blurry:
        line1 = 'Image blurred'
    elif sharpness_percent is None:
        line1 = 'Sharpness: --'
    else:
        line1 = f'Sharpness: {sharpness_percent}%'

    return line1, line2


def lcd_off():
    # Blank both lines and drop the HD44780's own display bit, so the panel
    # goes dark right away instead of freezing on whatever it was mid-render
    # when the shutdown signal arrived and staying lit until the Pi's power
    # actually cuts a few seconds later.
    lcd_write_line('', LINE1_ADDR)
    lcd_write_line('', LINE2_ADDR)
    lcd_send_byte(DISPLAY_OFF_CMD, is_data=False)


# systemd sends SIGTERM (not SIGINT) to stop this service, including during
# `poweroff`/`reboot` -- systemd stops services before the actual power-off
# happens, but Python doesn't turn SIGTERM into KeyboardInterrupt on its own,
# so without this the process was just killed mid-frame, leaving the LCD
# showing stale content until power cut rather than turning off first.
def handle_shutdown_signal(signum, frame):
    raise SystemExit(0)


signal.signal(signal.SIGTERM, handle_shutdown_signal)


def main():
    lcd_init()
    last_blurry = None
    last_sharpness_percent = None
    next_sharpness_check = 0.0
    try:
        while True:
            if not fetch_streaming():
                for label, message in STEPS:
                    display_step(label, message)
                    if fetch_streaming():
                        break
                continue

            now = time.monotonic()
            if now >= next_sharpness_check:
                last_blurry, last_sharpness_percent = fetch_sharpness()
                next_sharpness_check = now + SHARPNESS_POLL_INTERVAL_S

            line1, line2 = scan_lines(fetch_distance_cm(), last_blurry, last_sharpness_percent)
            lcd_write_line(line1, LINE1_ADDR)
            lcd_write_line(line2, LINE2_ADDR)
            time.sleep(SCAN_POLL_INTERVAL_S)
    except KeyboardInterrupt:
        pass
    finally:
        lcd_off()
        GPIO.cleanup()
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

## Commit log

2026-07-18 connected camera module 3
2026-07-18 models added
    [CameraExtras.stl, CoverExtras.stl, CoverLeft.stl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]
2026-07-18 Change Raspberry Pi OS to Lite and update URLs
    Updated Raspberry Pi OS version and adjusted access URLs for development and production.
2026-07-24 compile testing
    [coverextras2.stl]
2026-07-28 calibration changes
